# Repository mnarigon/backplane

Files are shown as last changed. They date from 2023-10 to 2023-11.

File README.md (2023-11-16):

# S-100 Bus Backplane

This repository contains the Kicad 7 design files for a 10-slot, Integrand chassis compatible, actively terminated S-100 bus backplane.

This design is in the prototype stage, where I am currently having the first boards manufactured. I will update as I test out the prototype.

I have received the rev --- prototype boards and done fit-checks on the footprints. I plan to test out the 2.7V supply circuitry using the rev --- prototype boards.

I spent some more time researching transmission line termination. I have concluded that providing active termination on the open-collector lines is beneficial. So, I have updated the design to rev A and provided active termination on all the non-power lines. I will wait until I check out the 2.7V supply circuitry to have rev A manufactured.

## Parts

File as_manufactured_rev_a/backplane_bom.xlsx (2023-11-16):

Backplane BOM Rev A
Designator | Part | Value | Footprint | Quantity | Digikey Part Number | Unit Price | Total
C1, C2, C3, C5, C7, C9 | Tantalum Capacitor | 1uF | CP_0805 | 6 | 718-2496-1-ND | $0.21 | $1.26
C4, C6, C8, C10 | Ceramic Capacitor | 0.01uF | C_0805 | 4 | 490-8607-1-ND | $0.01 | $0.04
D1-D3 | LED | Green | LED_0805 | 3 | 732-4983-1-ND | $0.19 | $0.57
D4 | Zener Diode | 5.1V | D_SOD-323 | 1 | MM3Z5V1ST1GOSCT-ND | $0.14 | $0.14
J1 | Header |  | AMP_640445-4 | 1 | A1972-ND | $0.27 | $0.27
J2 | Header |  | AMP_640445-3 | 1 | A19890-ND | $0.26 | $0.26
J3 | Header |  | AMP_640454-2 | 1 | A19423-ND | $0.15 | $0.15
J1 Mating Connector | Connector |  |  | 1 | A24113-ND | $0.25 | $0.25
J2 Mating Connector | Connector |  |  | 1 | A24112-ND | $0.20 | $0.20
J3 Mating Connector | Connector |  |  | 1 | A99613-ND | $0.15 | $0.15
J1, J2 Mating Connector Contacts | Contact |  |  | 7 | A31396-ND | $0.35 | $2.45
J3 Mating Connector Contacts | Contact |  |  | 2 | A100453CT-ND | $0.10 | $0.20
P1-P10 | Edge Connector |  | EDAC_346-100-520-202 | 10 | EDC346102-ND or ESA50DRSH-S288-ND | $15.48 | $154.80
Q1 | Transistor | BC858 | SOT-23-3 | 1 | BC858BLT3GOSCT-ND | $0.11 | $0.11
Q2 | Transistor | TIP29 | TO-220-3_Horizontal | 1 | TIP29CGOS-ND | $1.11 | $1.11
Q3 | Transistor | TIP30 | TO-220-3_Horizontal | 1 | TIP30CGOS-ND | $0.61 | $0.61
Q4 | Transistor | BC848 | SOT-23-3 | 1 | BC848BLT3GOSCT-ND | $0.13 | $0.13
Q2, Q3 Mount Kit | Mount Kit |  |  | 2 | 4880MG-ND | $3.20 | $6.40
R1, R2 | Resistor | 3.0K | R_0805 | 2 | RMCF0805JT3K00CT-ND | $0.02 | $0.04
R3 | Resistor | 1.2K | R_0805 | 1 | RMCF0805JT1K20CT-ND | $0.02 | $0.02
R4-R6 | Resistor | 1.5K | R_0805 | 3 | RMCF0805JT1K50CT-ND | $0.02 | $0.06
R7, R12 | Resistor | 1.0K | R_0805 | 2 | RMCF0805FT1K00CT-ND | $0.02 | $0.04
R10, R11 | Resistor | 910 | R_0805 | 2 | 738-RMCF0805FT910RCT-ND | $0.02 | $0.04
RN1-RN46 | Resistor Array | 560 | R_Array_Convex_4x1206 | 46 | CAY16-561J4LFCT-ND | $0.04 | $1.84
RV1 | Potentiometer | 2.0K | Bourns_TC33 | 1 | TC33X-202ECT-ND | $0.28 | $0.28
U1 | Operational Amplifier | LM7301 | SOT-23-5 | 1 | 488-LM7301SN1T1GCT-ND | $0.76 | $0.76
Total |  |  |  |  |  |  | $172.39

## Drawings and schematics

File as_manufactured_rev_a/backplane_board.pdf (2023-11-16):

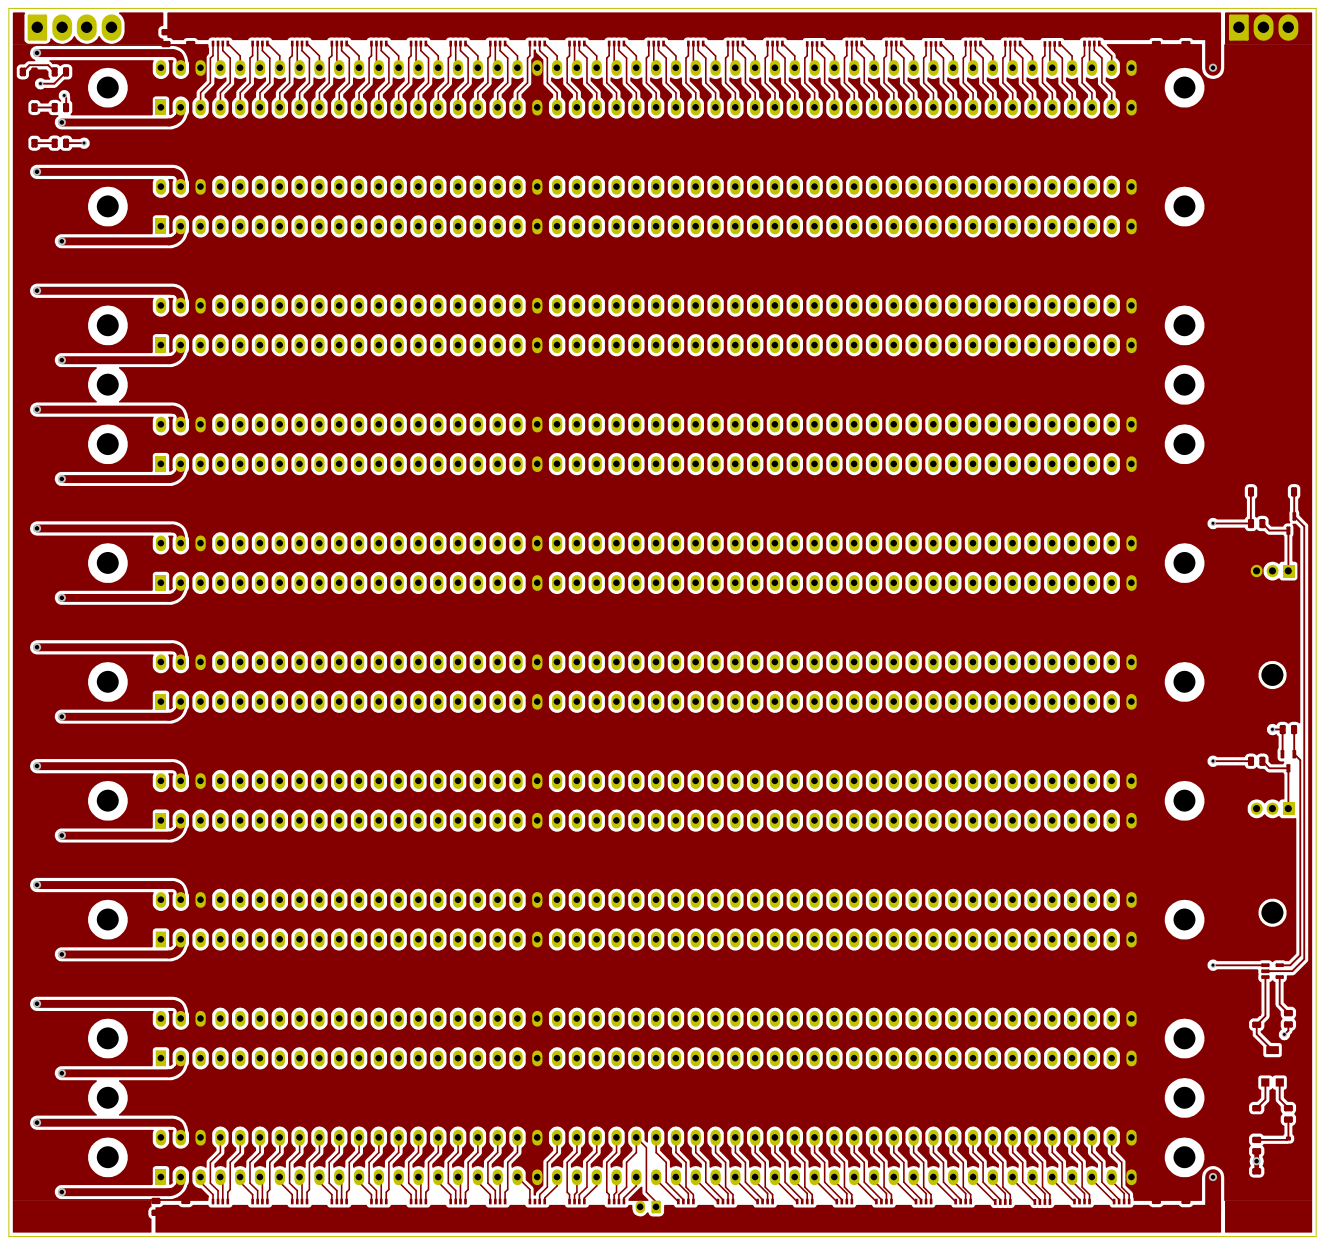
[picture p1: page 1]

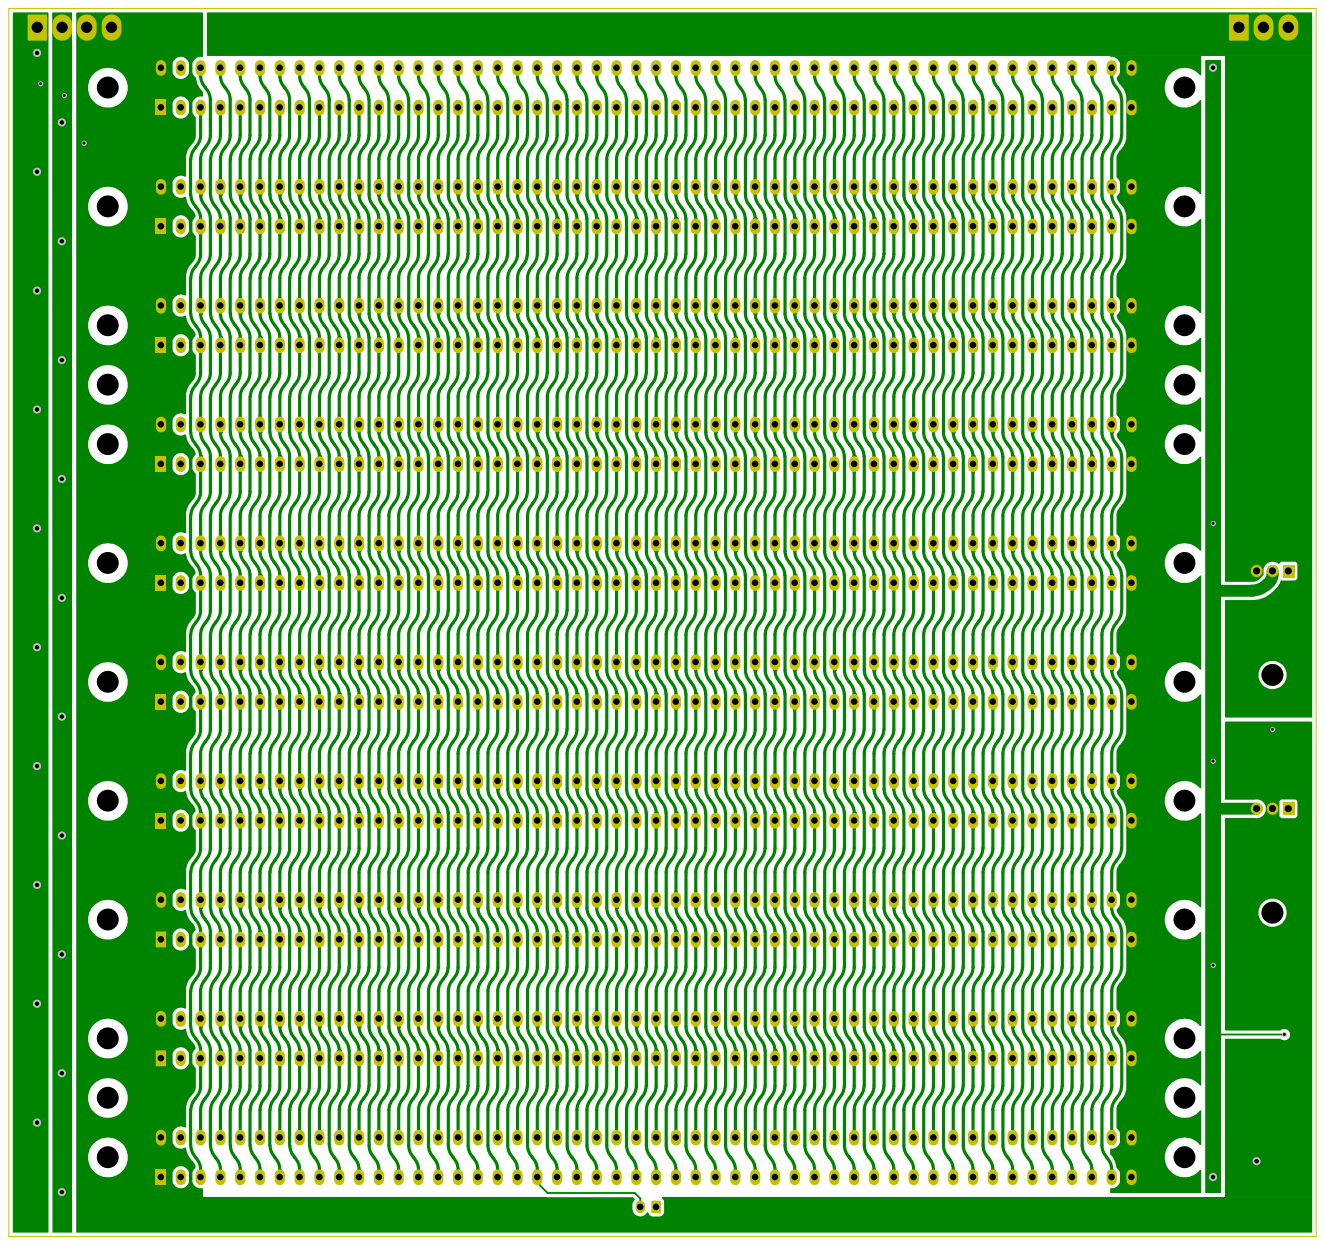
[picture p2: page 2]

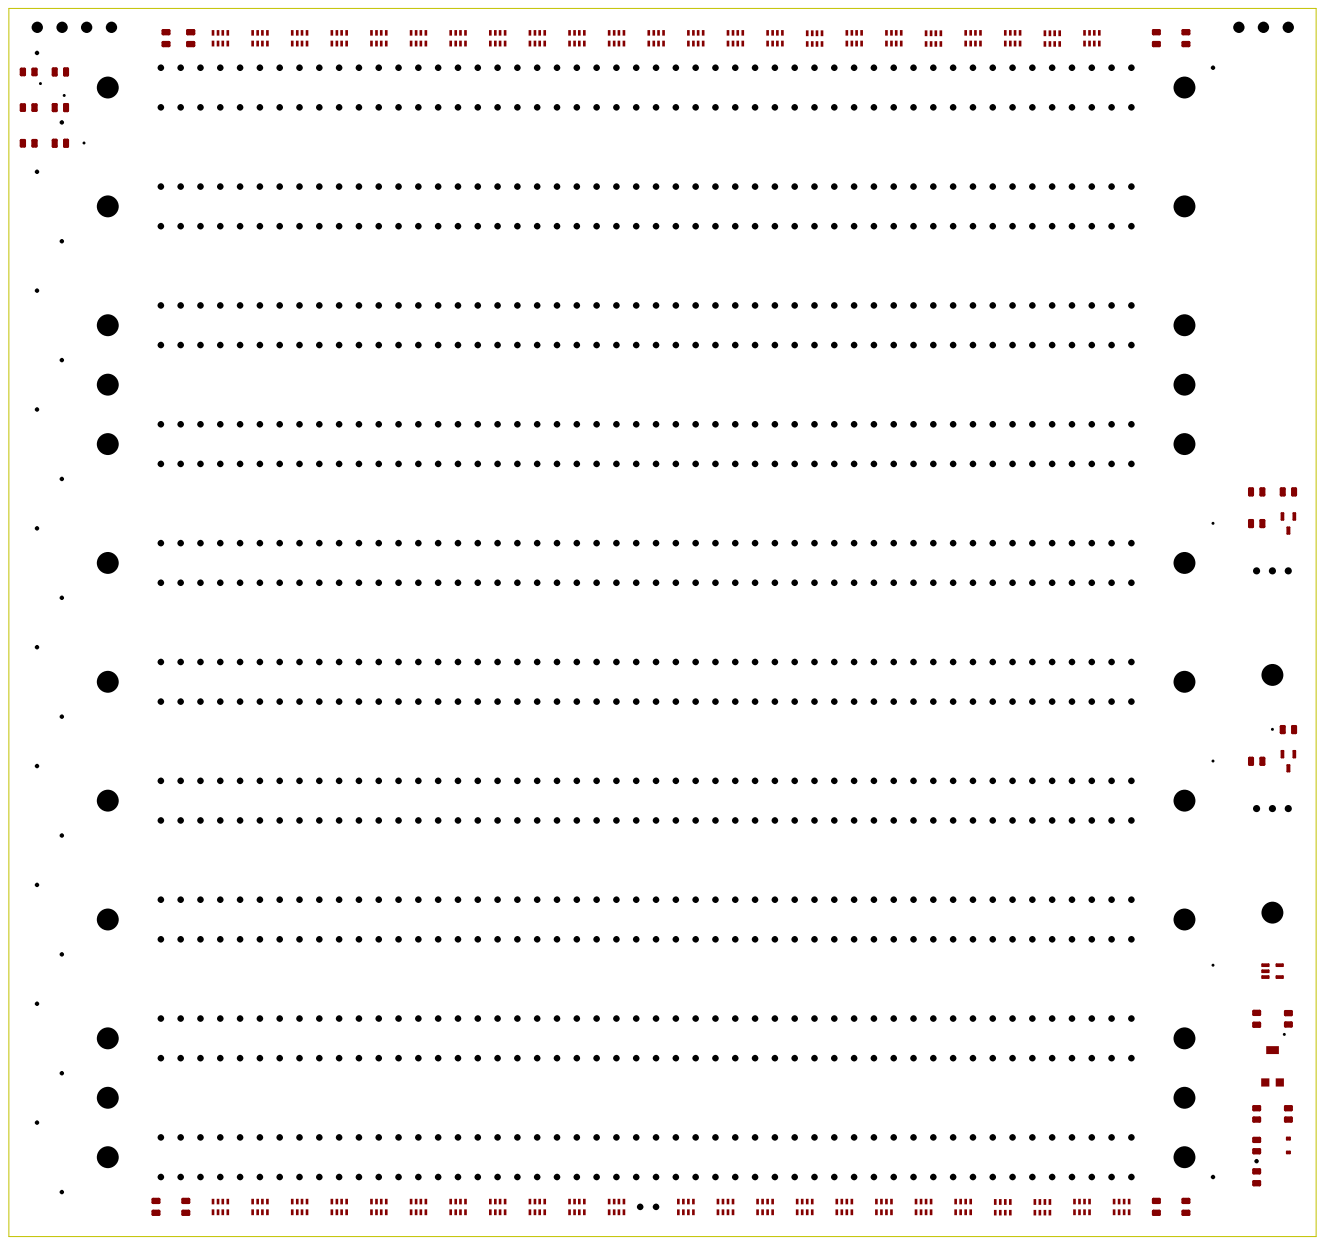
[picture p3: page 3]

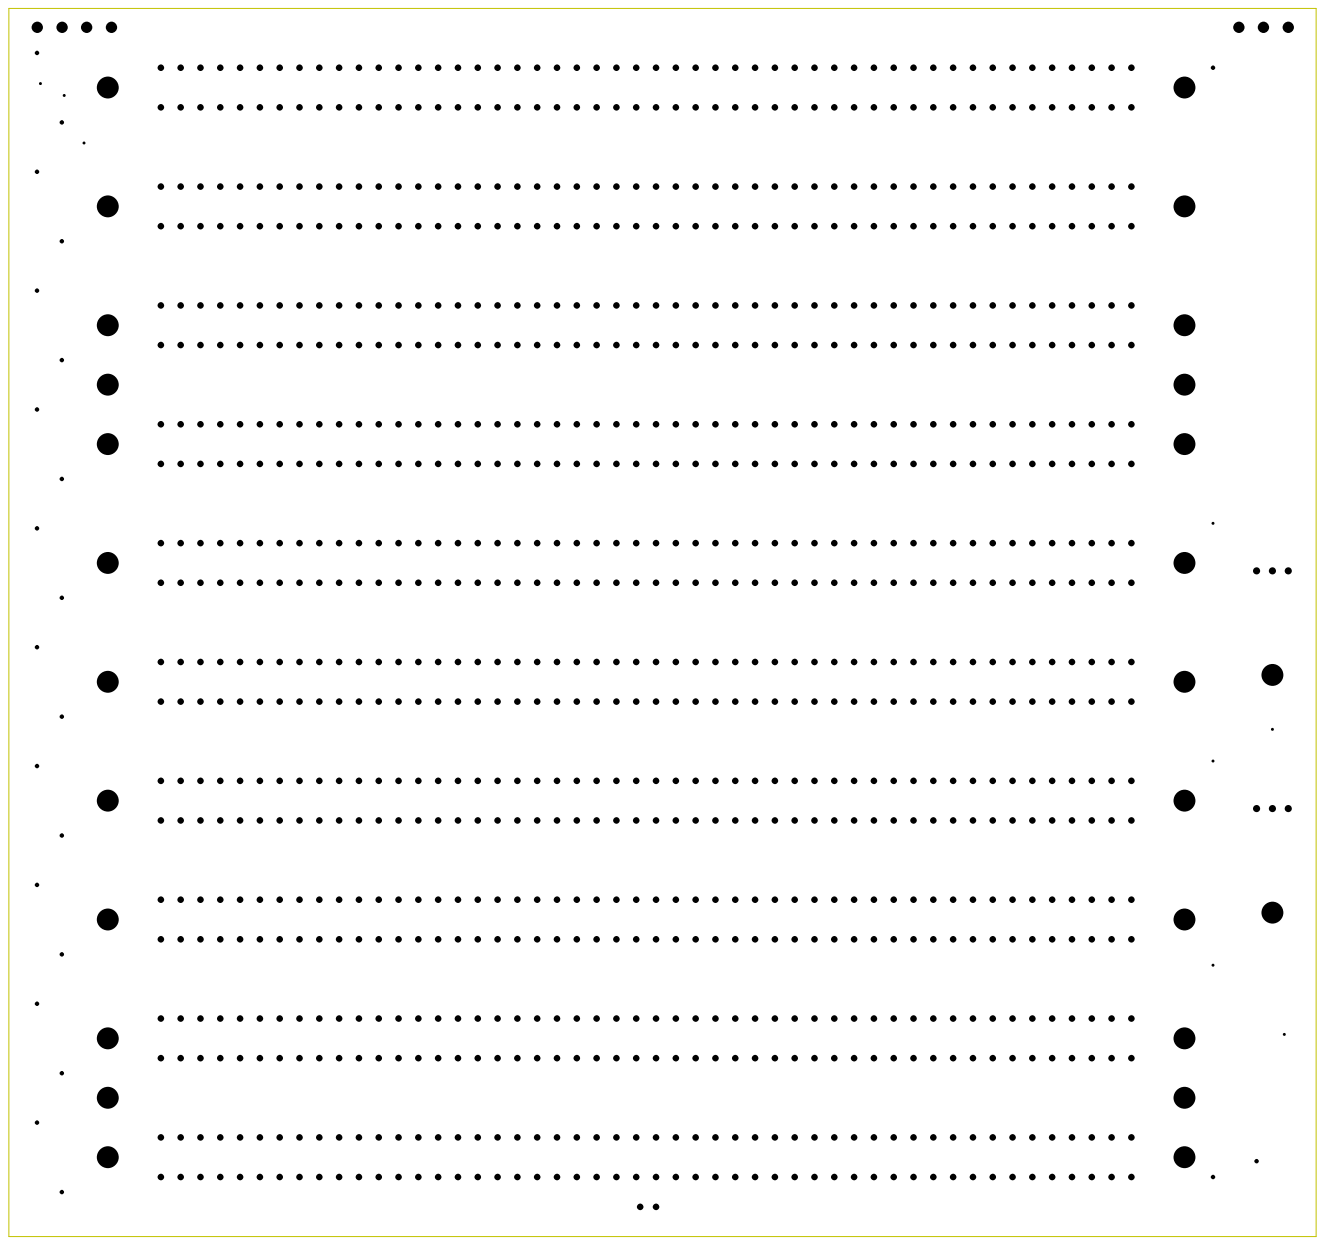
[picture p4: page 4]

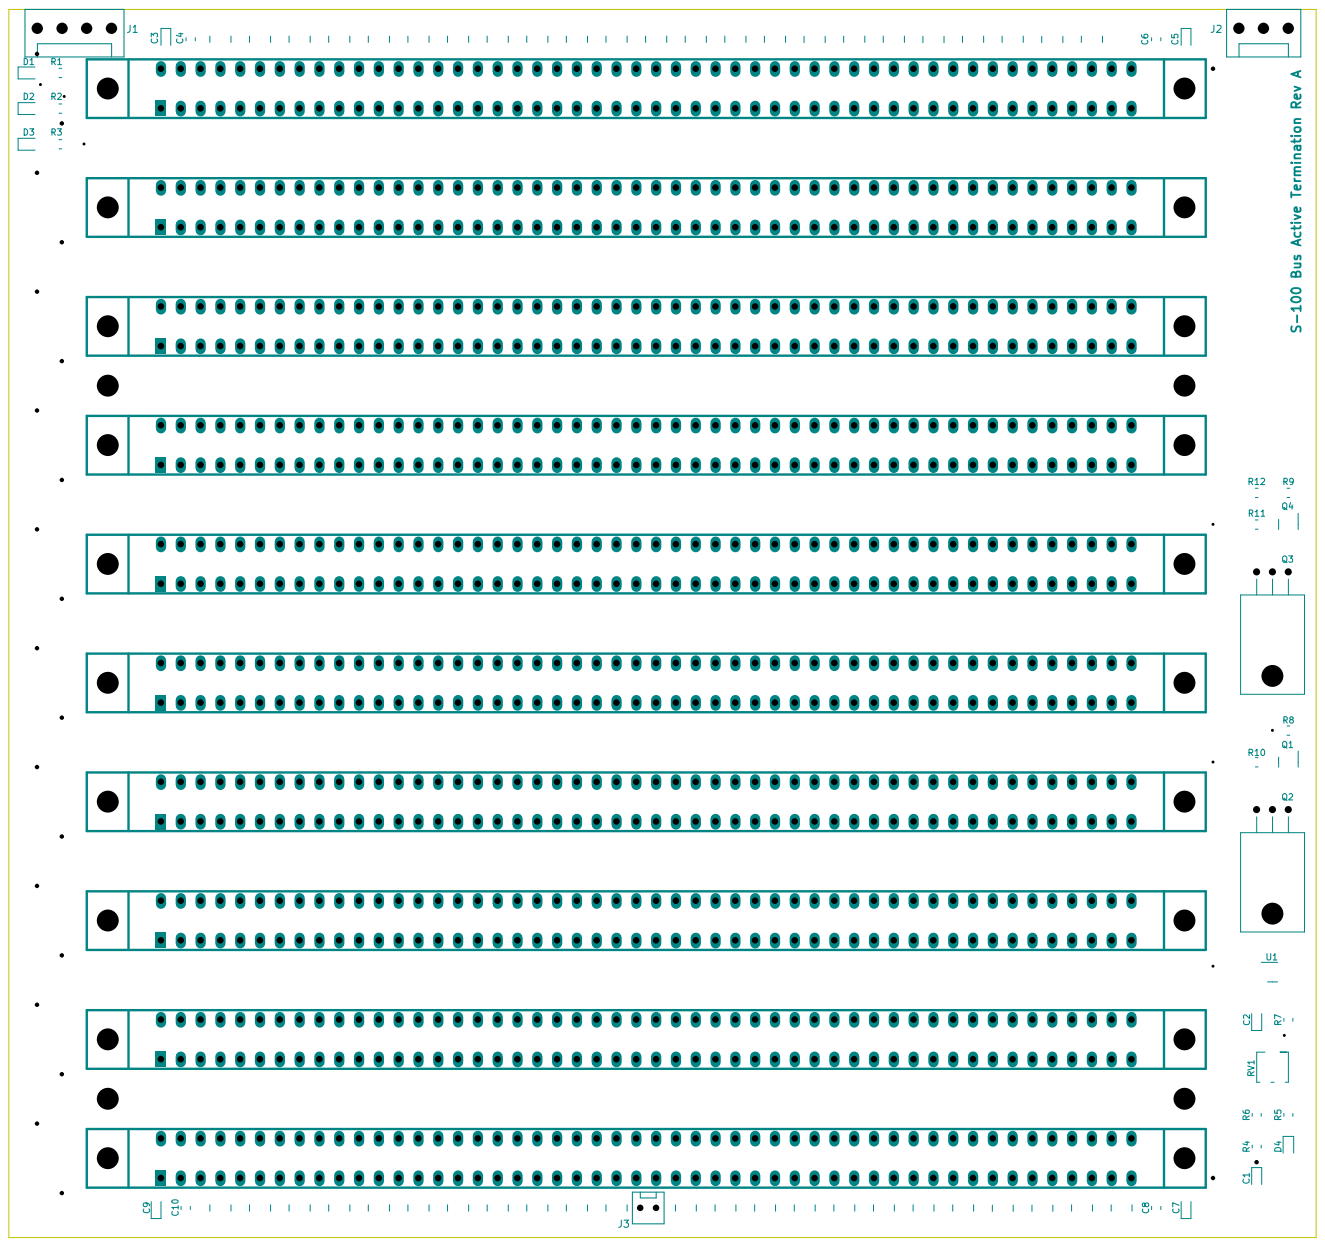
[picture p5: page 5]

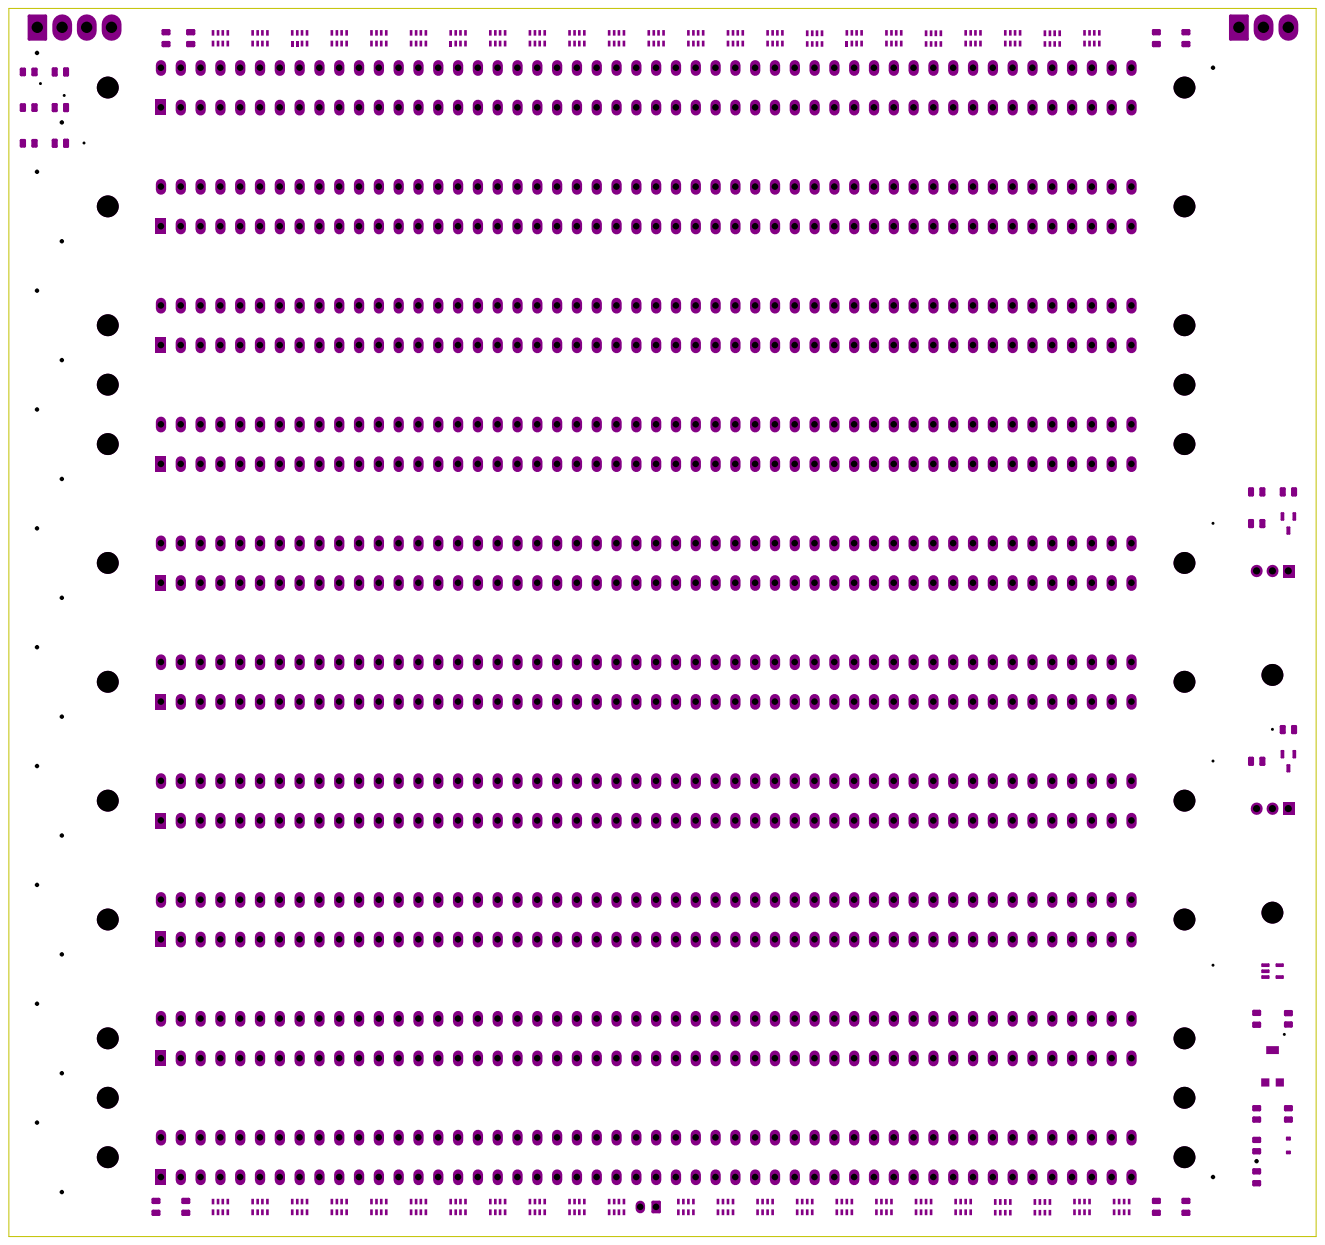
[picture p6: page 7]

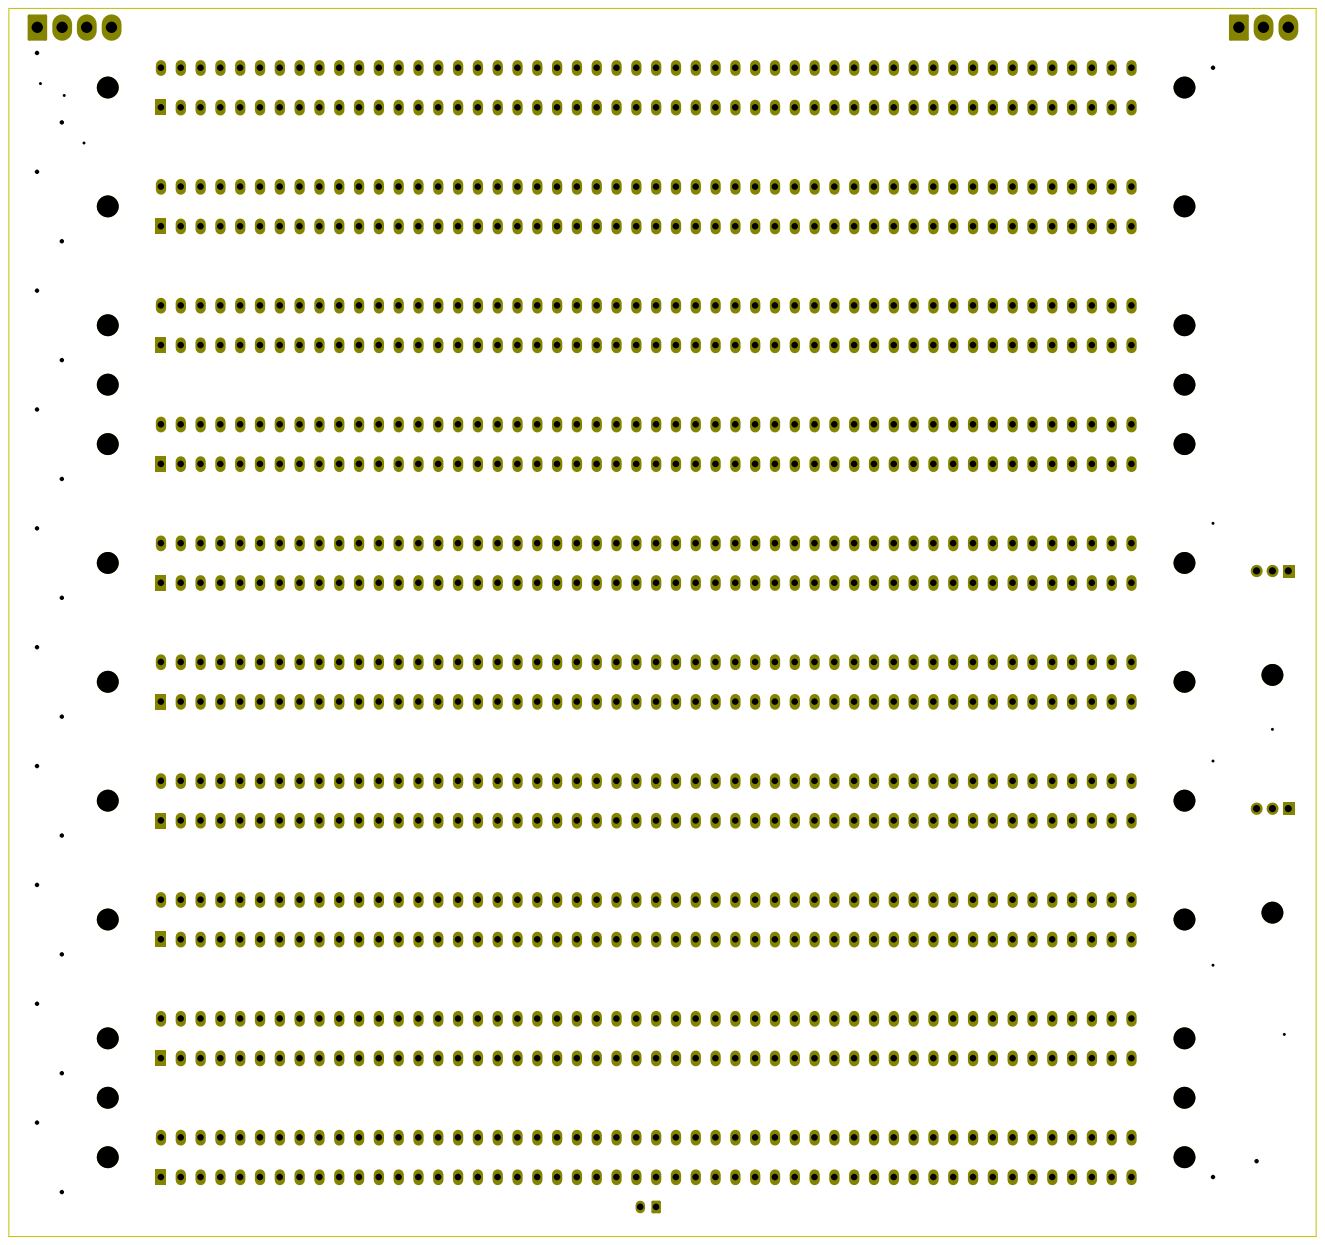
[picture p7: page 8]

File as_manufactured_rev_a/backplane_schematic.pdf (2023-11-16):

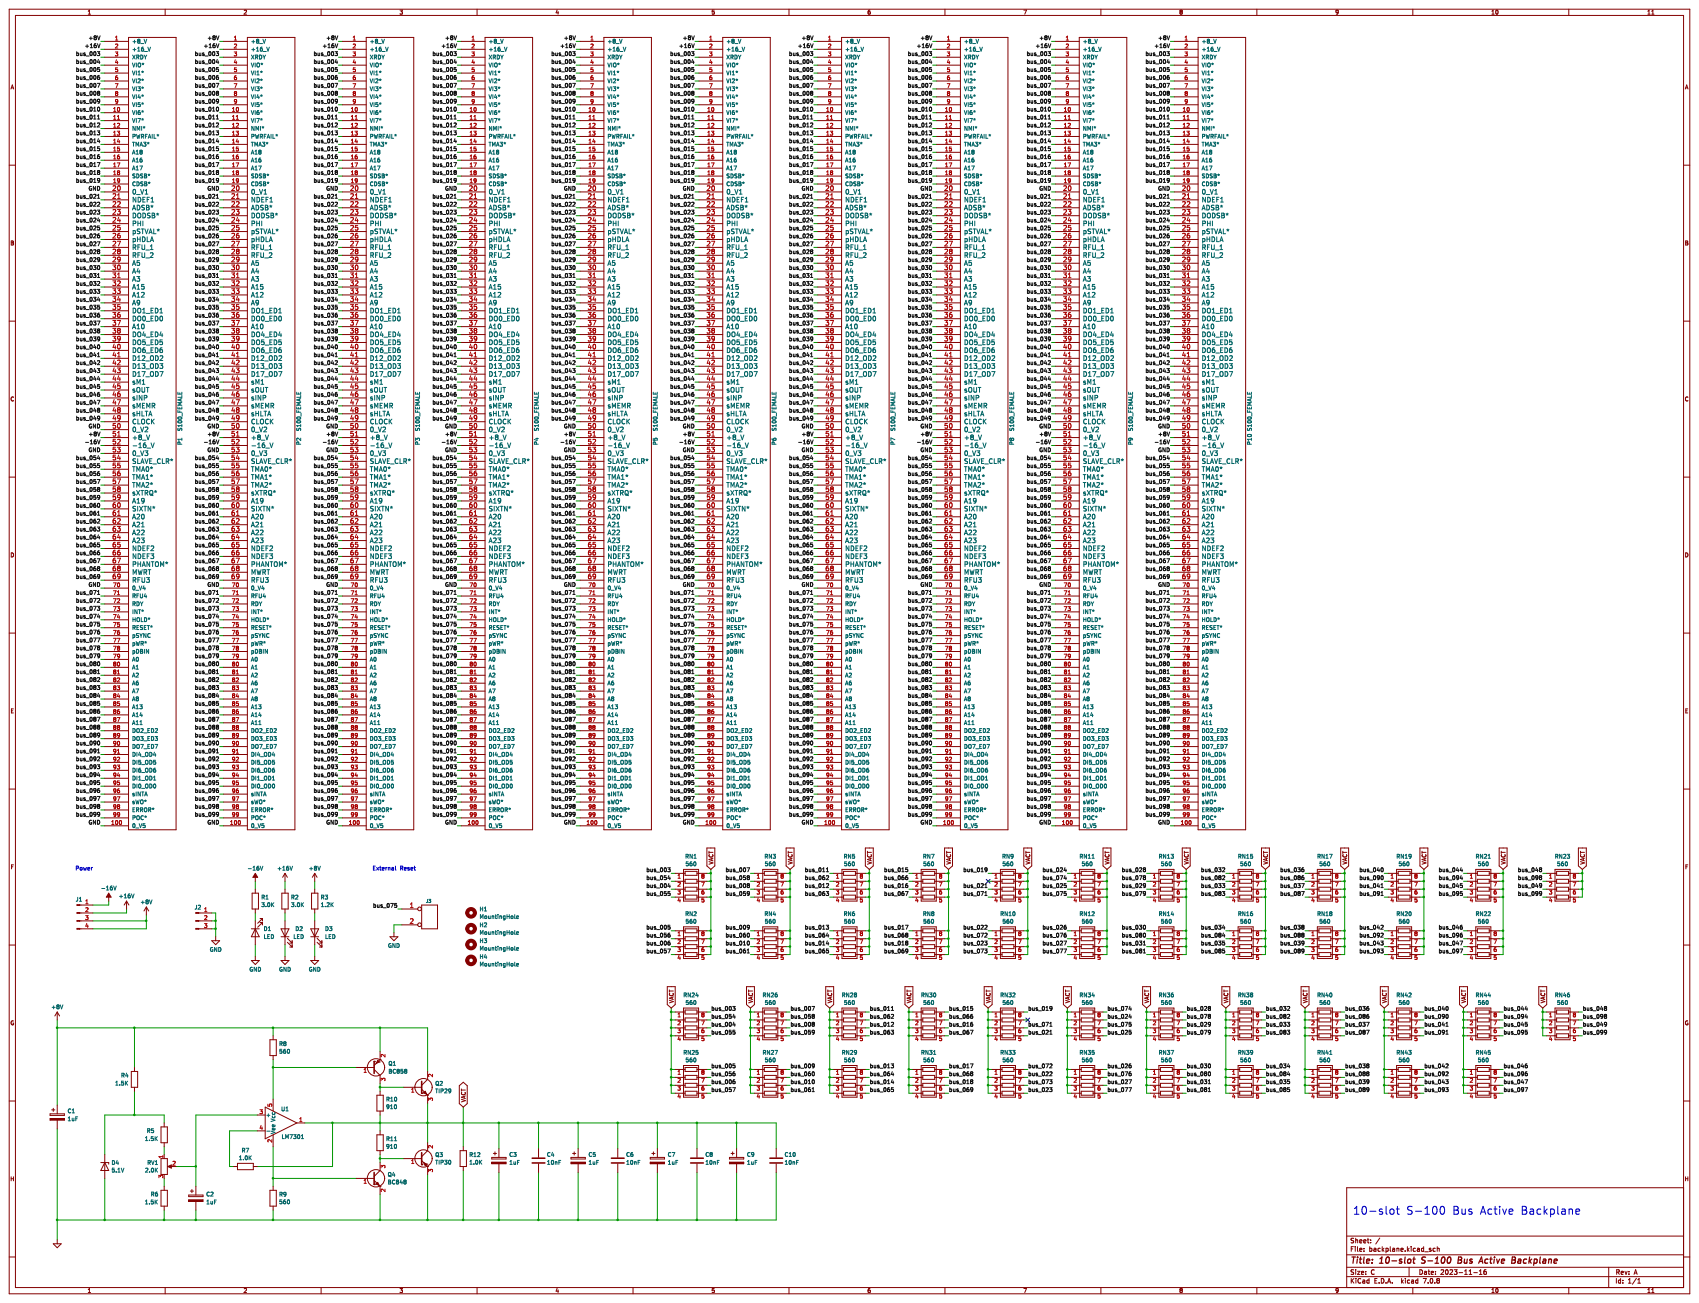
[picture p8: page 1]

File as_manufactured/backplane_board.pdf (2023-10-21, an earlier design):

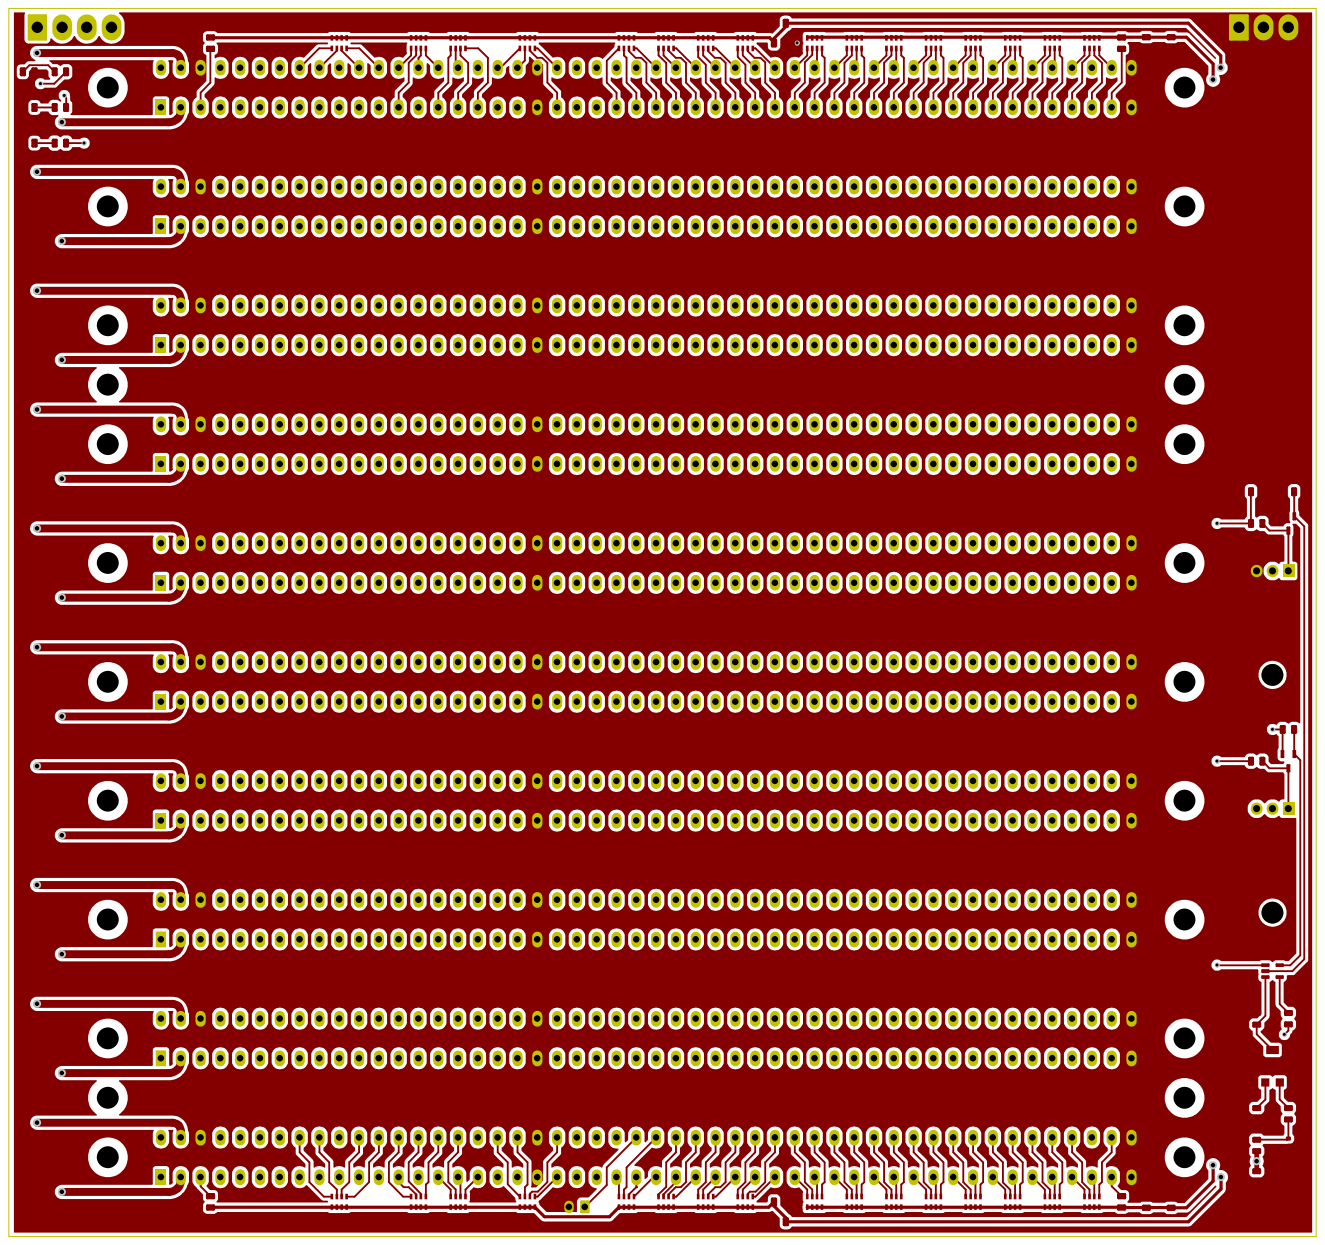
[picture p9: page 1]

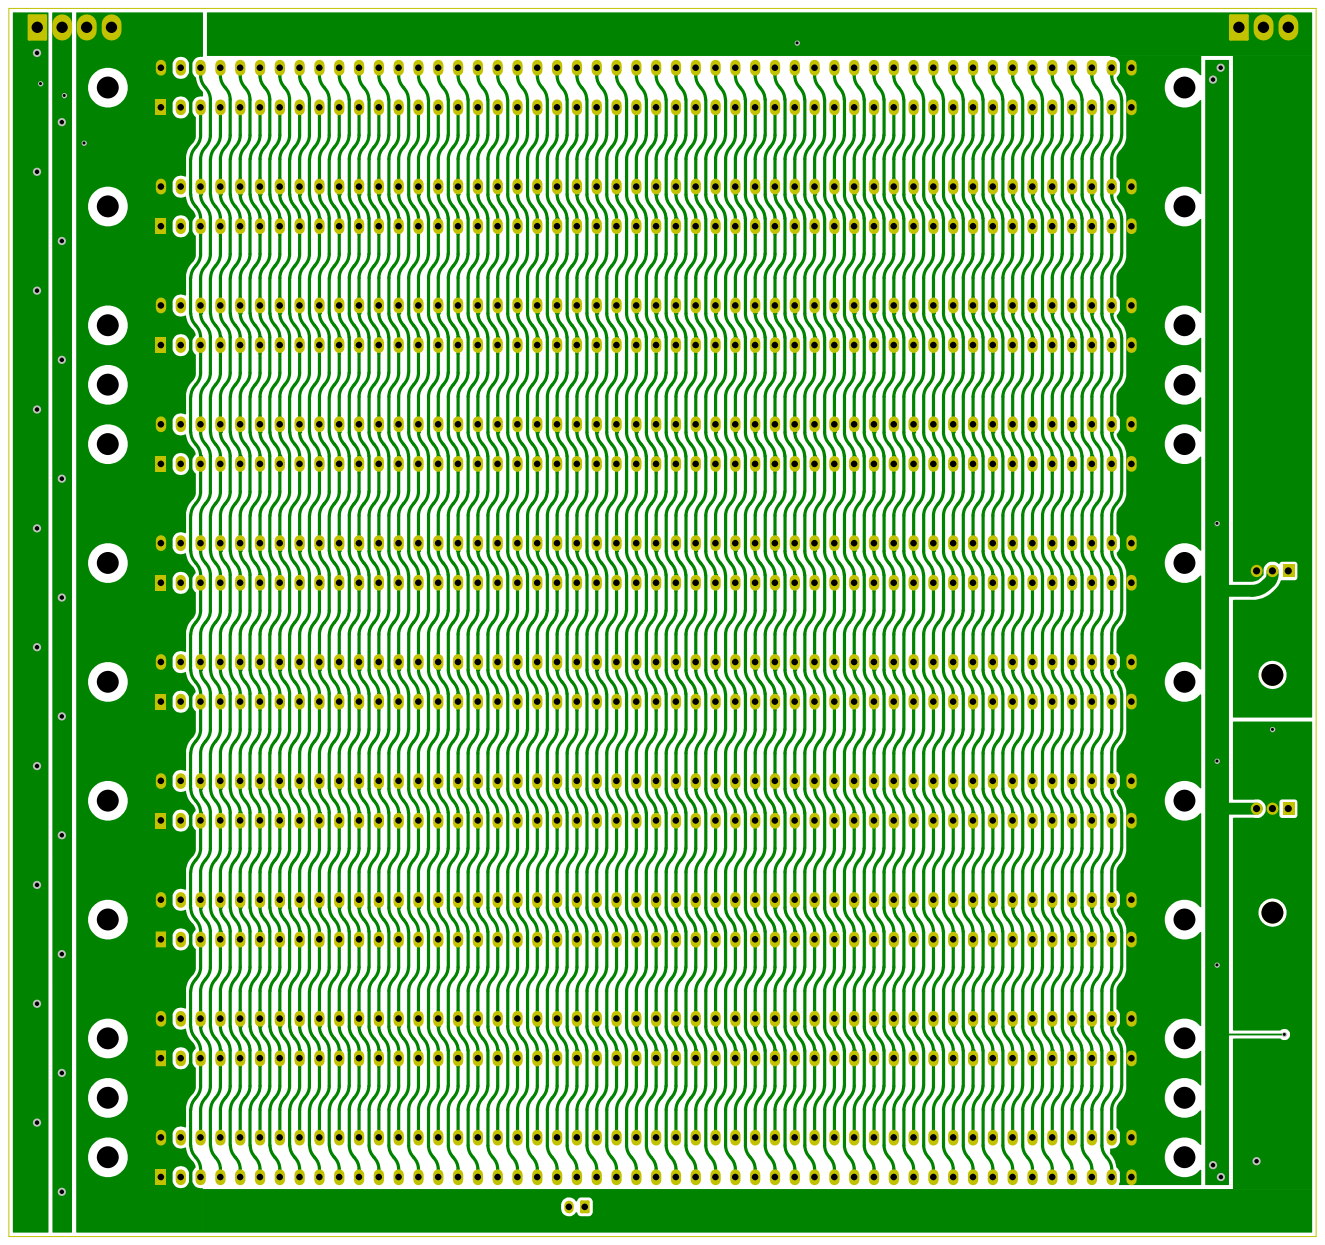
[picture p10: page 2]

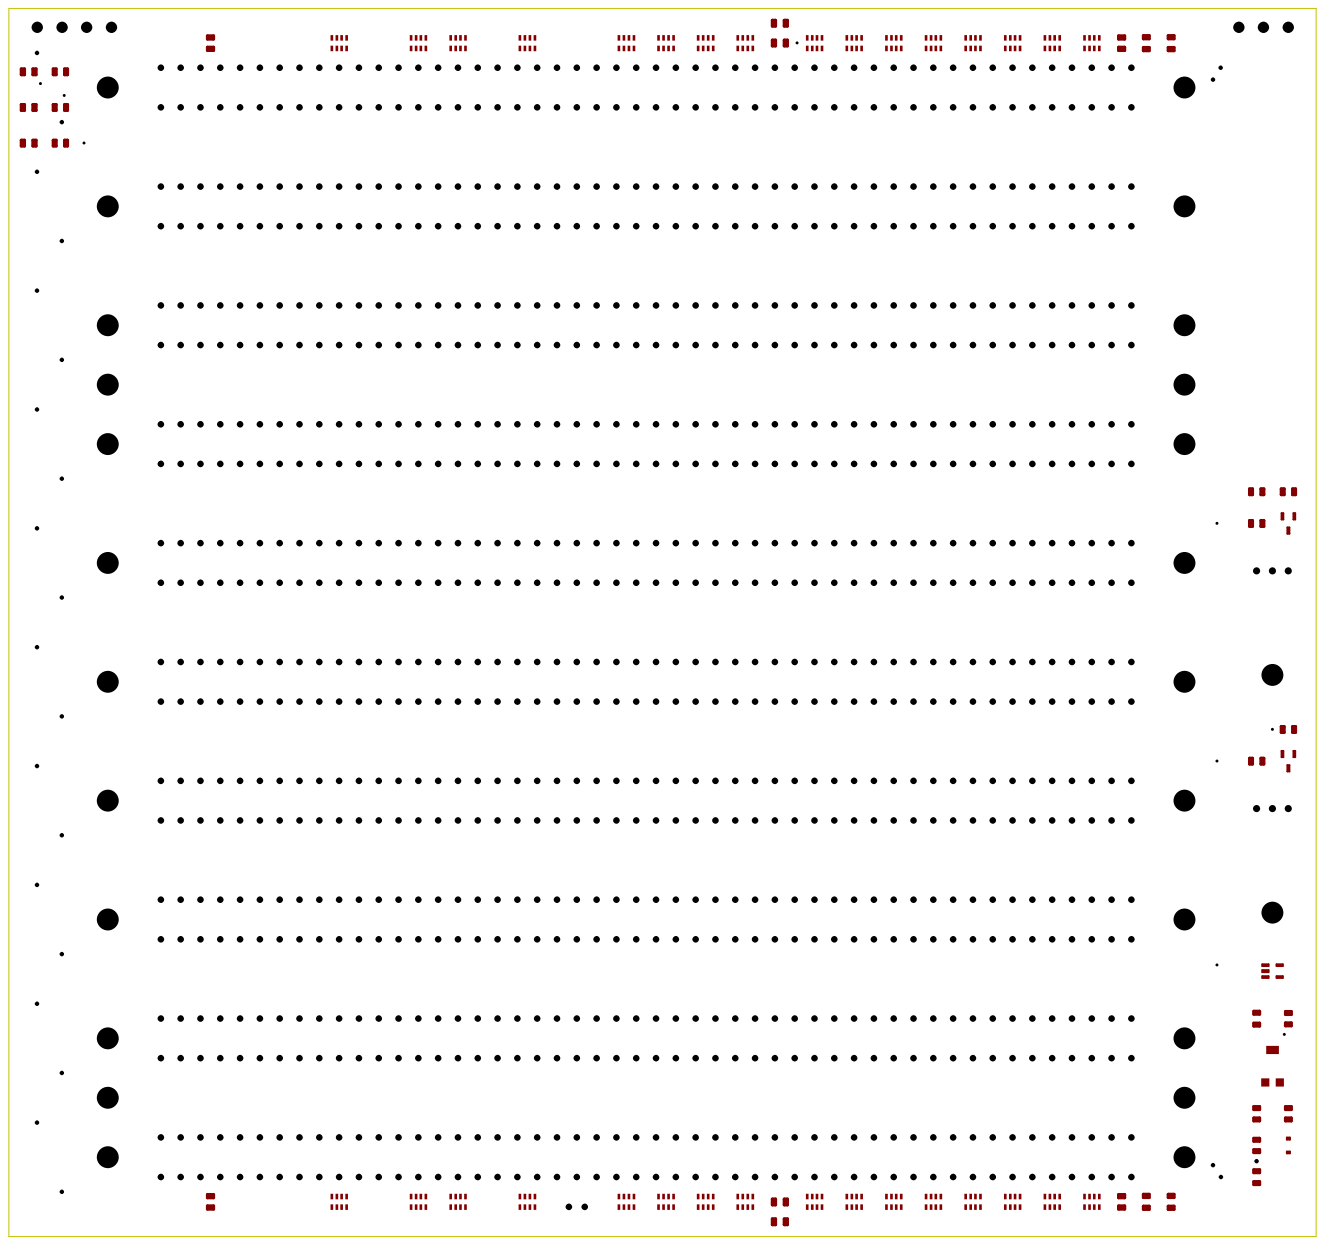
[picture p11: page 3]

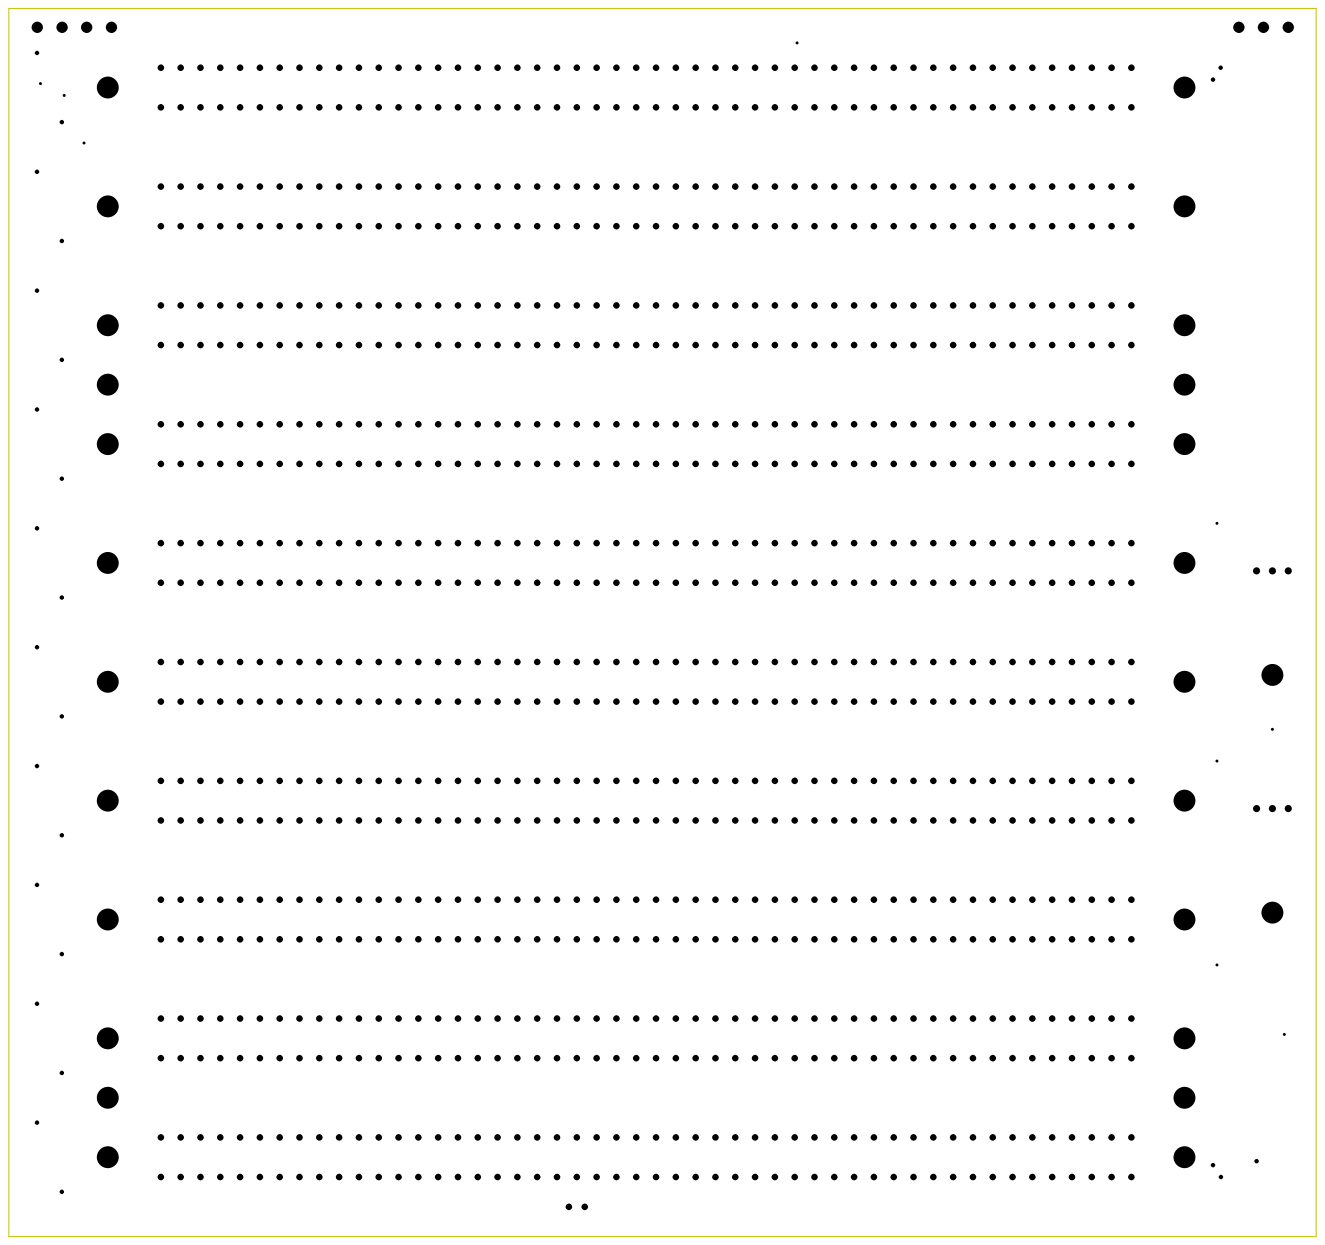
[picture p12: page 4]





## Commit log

2023-10-21 initial import
    [backplane.kicad_sch, backplane_bom.csv]
2023-11-16 Update to rev A to provide active termination on all non-power lines.
    [backplane.kicad_sch, backplane_bom.xlsx]
